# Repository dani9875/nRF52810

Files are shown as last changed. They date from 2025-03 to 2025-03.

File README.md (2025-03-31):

# nRF52810
Basic HW and FW to setup nRF developer environment

# Instructions

1. Clone the repository:
```bash
git clone <repository-url>
```

2. Build the Docker image (requires sudo permissions):
```bash
sudo ./docker_build.sh
```
3. Start the Docker container:

```bash
./docker_start.sh
```

4. Enter the project root folder (you should already be in the correct directory).

5. Initialize the West workspace:
```bash
west init -l app
```

6. Update west modules (this step can take a few minutes)
```bash
west update
```

7. Export Zephyr environment:
```bash
west zephyr-export
```

8. Build the application for the nRF52840 DK:
```bash
west build -b nrf52840dk/nrf52840 app
```

## Release notes

### Version: v2.0-test phase
Changelog:
- 2.4 GHz antenna design
- LED for blinky funtionality
- Plug of nails changed to pluggable
- Optical sensor added
- 3V3 and 1V9 power rails
- KiCAD library commit: f8f82b3228b9b2e6a28c75499dfac7be01fe0e7f

### Version: v1.0
Changelog:
- Minimal env. for bringing an nRF52810 up
- LED for blinky functionality
- Tactile button for user input
- LDO power adjustment
- Plug of nails footprint faulty

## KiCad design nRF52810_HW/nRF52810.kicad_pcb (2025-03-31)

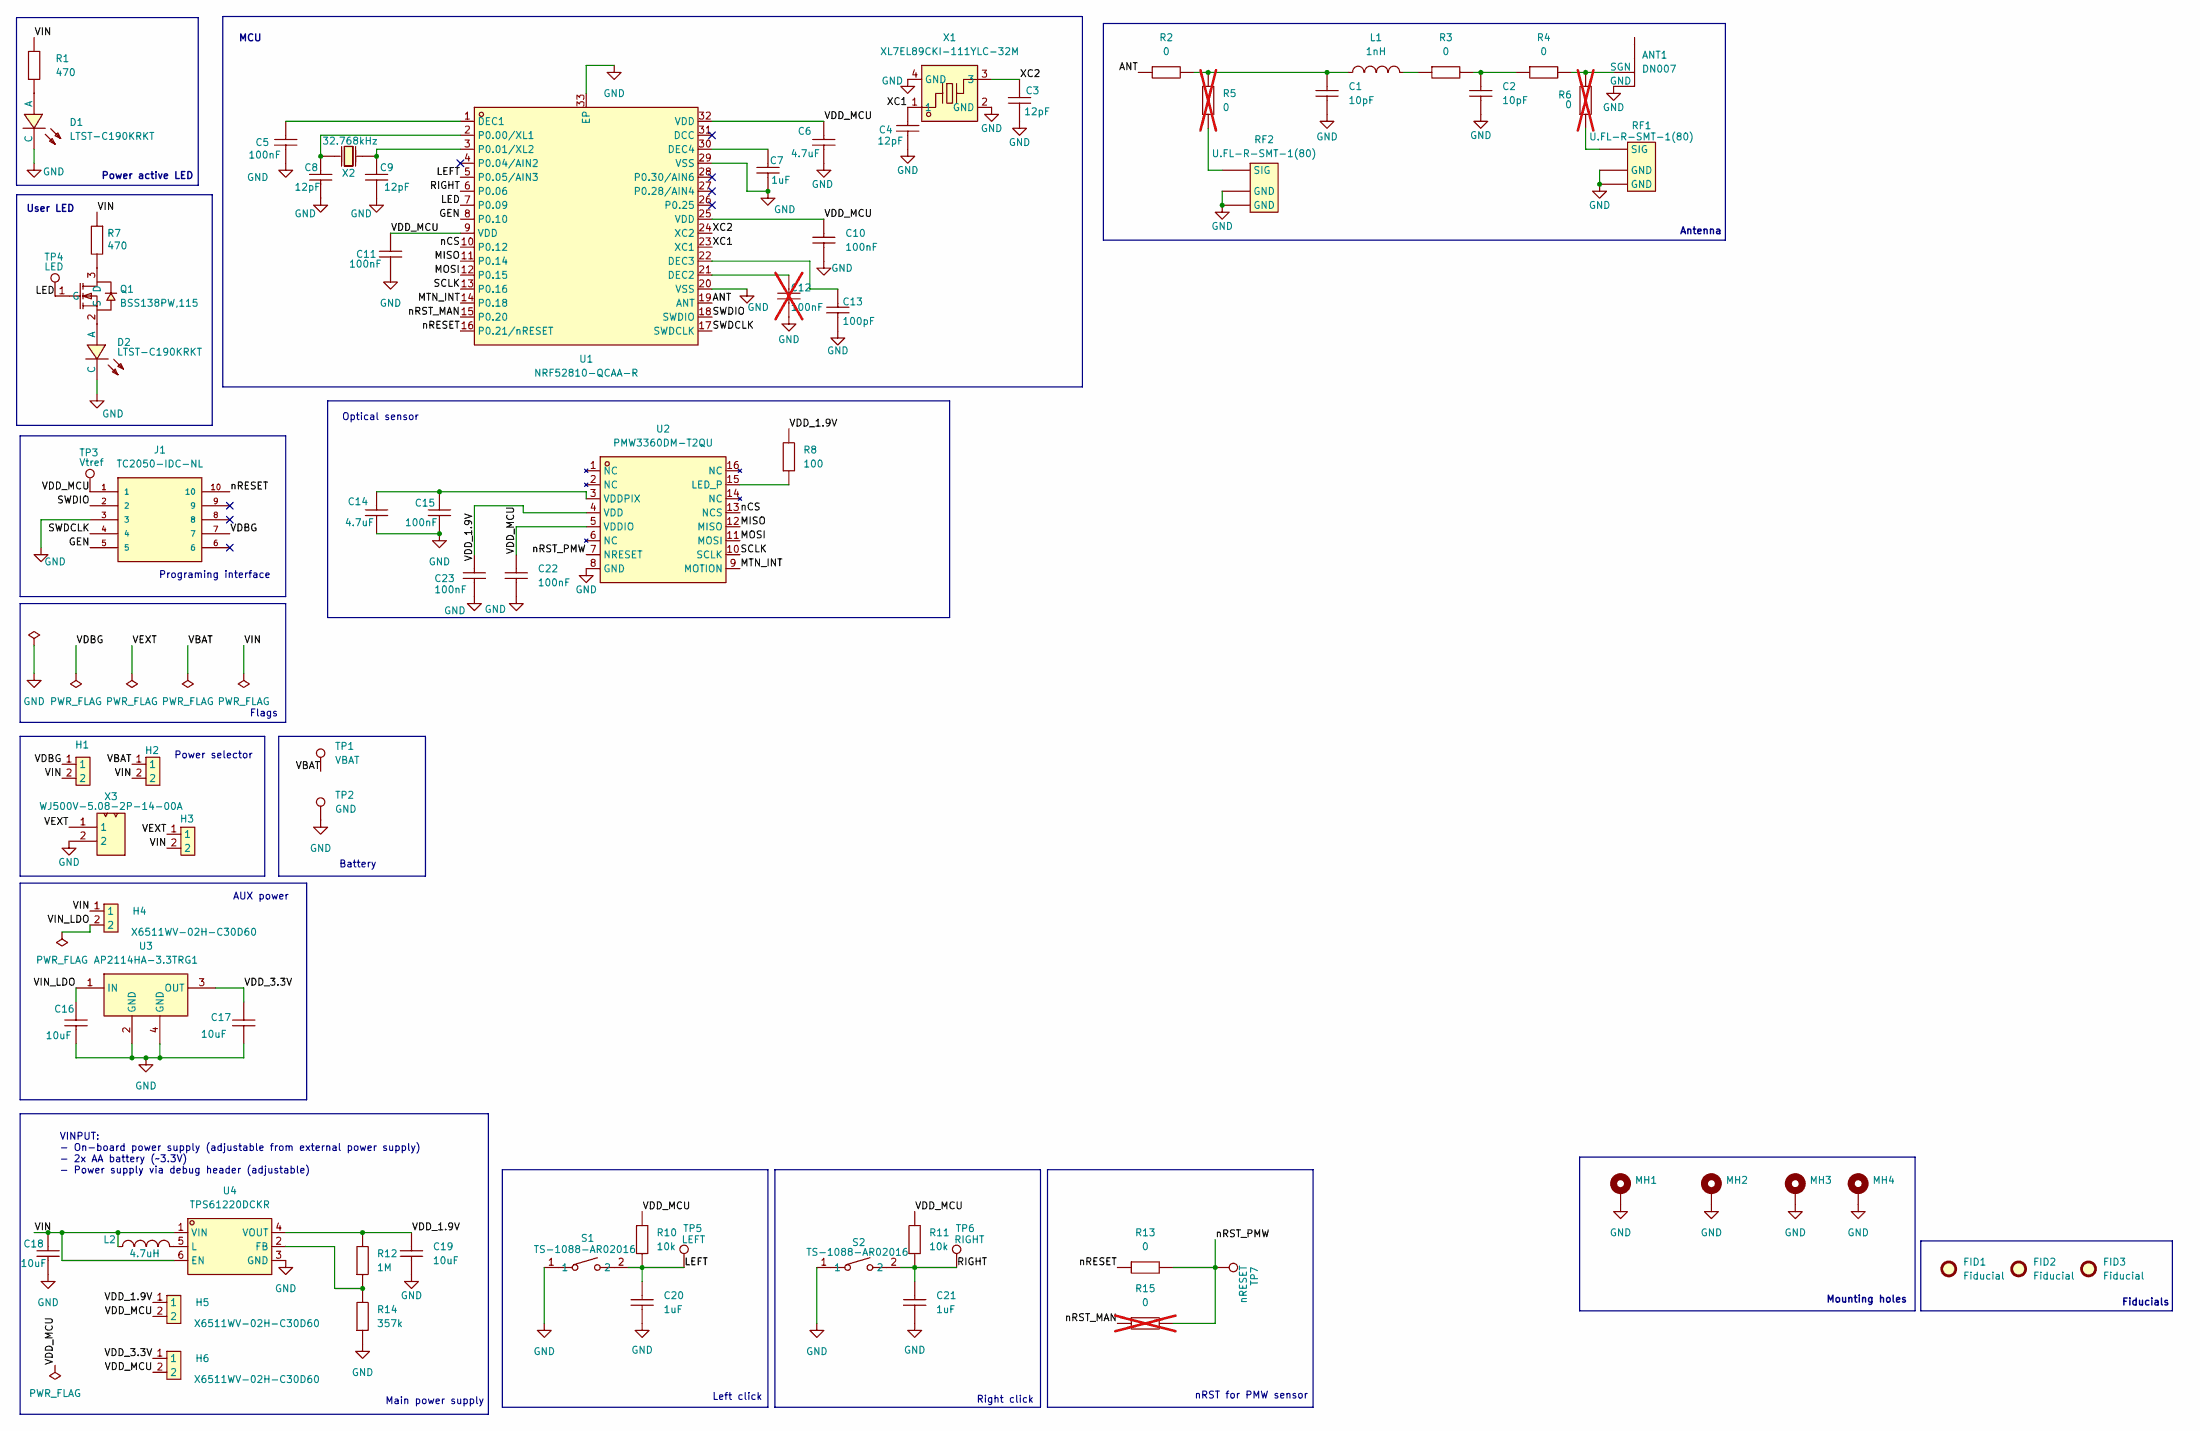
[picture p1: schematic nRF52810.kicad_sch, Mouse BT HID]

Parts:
ANT1: DN007; [ANTENNA]DN007_1,2.4GHz
C1, C2: C0805C100K5GACTU; [CAP_SMD_0805_2012Metric]; LCSC Part C2181972
C3, C4, C8, C9: C0805C120J5GACAUTO; [CAP_SMD_0805_2012Metric]; LCSC Part C3844403
C5, C10, C11, C15, C22, C23: CC0805KRX7R9BB104; [CAP_SMD_0805_2012Metric]; LCSC Part C49678
C6, C14: CL21A475KAQNNNE; [CAP_SMD_0805_2012Metric]; LCSC Part C1779
C7, C20, C21: C0805C105M4VACTU; [CAP_SMD_0805_2012Metric]; LCSC Part C2171722
C12: CC0805KRX7R9BB104; [CAP_SMD_0805_2012Metric]; LCSC Part C49678; not fitted
C13: C0805C101K5GACTU; [CAP_SMD_0805_2012Metric]; LCSC Part C452752
C16, C17, C18, C19: CL21A106KOQNNNE; [CAP_SMD_0805_2012Metric]; LCSC Part C1713
D1, D2: LTST-C190KRKT; [LED]Lite-On LTST-C190KRKT; LCSC Part C94869
FID1, FID2, FID3: Fiducial; Fiducial_0.5mm_Mask1mm
H1, H2, H3, H4, H5, H6: X6511WV-02H-C30D60; [2x1_PIN_HEADER_STR]XKB Connection X6511WV-02H-C60D30; LCSC Part C706874
J1: TC2050-IDC-NL; [PLUG_OF_NAILS_10P]TC2050_IDC_NL; PARTREV A
L1: LQG15HS1N0S02D; [IND_SMD_0402_1005Metric]; LCSC Part C18222
L2: FNR3015S4R7MT; [POWER_IND]cjiang (Changjiang Microelectronics Tech) FNR301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; LCSC Part C167753
MH1, MH2, MH3, MH4: [MOUNTING_HOLE]MountingHole_2.2mm_M2_DIN965_Pad
Q1: BSS138PW,115; [NMOS]Nexperia BSS138PW,115; LCSC Part C193366
R1, R7: 0805W8F4700T5E; [RES_SMD_0805_2012Metric]; LCSC Part C17710
R2, R3, R4: 0402WGF0000TCE; [RES_SMD_0402_1005Metric]; LCSC Part C17168
R5, R6: 0402WGF0000TCE; [RES_SMD_0402_1005Metric]; LCSC Part C17168; not fitted
R8: 0805W8F1000T5E; [RES_SMD_0805_2012Metric]; LCSC Part C17408
R10, R11: 0805W8F1002T5E; [RES_SMD_0805_2012Metric]; LCSC Part C17414
R12: 0805W8F1004T5E; [RES_SMD_0805_2012Metric]; LCSC Part C17514
R13: 0805W8F0000T5E; [RES_SMD_0805_2012Metric]; LCSC Part C17673
R14: RK73H2ATTD3573F; [RES_SMD_0805_2012Metric]; LCSC Part C317468
R15: 0805W8F0000T5E; [RES_SMD_0805_2012Metric]; LCSC Part C17673; not fitted
RF1, RF2: U.FL-R-SMT-1(80); [SMD_COAXIAL_CONNECTOR]HRS(Hirose) U.FL-R-SMT-1(80); LCSC Part C88374
S1, S2: TS-1088-AR02016; [TACTILE_SWITCH]XUNPU TS-1088-AR02016; LCSC Part C720477
TP1: VBAT; [TEST_POINT]TestPoint_Pad_2.0x2.0mm
TP2: GND; [TEST_POINT]TestPoint_Pad_2.0x2.0mm
TP3: Vtref; [TEST_POINT]TestPoint_Pad_D1.0mm
TP4: LED; [TEST_POINT]TestPoint_Pad_D1.0mm
TP5: LEFT; [TEST_POINT]TestPoint_Pad_D1.0mm
TP6: RIGHT; [TEST_POINT]TestPoint_Pad_D1.0mm
TP7: nRESET; [TEST_POINT]TestPoint_Pad_D1.0mm
U1: NRF52810-QCAA-R; [MCU]Nordic Semicon nRF52810-QCAA-R; LCSC Part C519278
U2: PMW3360DM-T2QU; [OPTICAL_NAVIGATION_CHIP]PixArt PMW3360DM-T2QU; LCSC Part C20612443
U3: AP2114HA-3.3TRG1; [LDO]Diodes Incorporated AP2114HA-3.3TRG1; LCSC Part C460314
U4: TPS61220DCKR; [BOOST_CONV]Texas Instruments TPS61220DCKR; LCSC Part C15421
X1: XL7EL89CKI-111YLC-32M; [Crystal_32_MHz]YXC XL7EL89CKI-111YLC-32M; LCSC Part C2965582
X2: SC-20S32.768kHz20PPM9pF; [Crystal_32_768_kHZ]Seiko SC-20S,32.768kHz,20PPM,9pF; LCSC Part C97603
X3: WJ500V-5.08-2P-14-00A; [1x2_SCREW_TERMINAL_BLOCK]Ningbo Kangnex Elec WJ500V-5.08-2P; LCSC Part C8465

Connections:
/ANT: R2.1, U1.19 (ANT)
/GEN: J1.5, U1.8 (P0.10)
/LED: Q1.1 (G), TP4.1, U1.7 (P0.09)
/LEFT: C20.2, R10.1, S1.2, TP5.1, U1.5 (P0.05/AIN3)
/MISO: U1.11 (P0.14), U2.12 (MISO)
/MOSI: U1.12 (P0.15), U2.11 (MOSI)
/MTN_INT: U1.14 (P0.18), U2.9 (MOTION)
/RIGHT: C21.2, R11.1, S2.2, TP6.1, U1.6 (P0.06)
/SCLK: U1.13 (P0.16), U2.10 (SCLK)
/SWDCLK: J1.4, U1.17 (SWDCLK)
/SWDIO: J1.2, U1.18 (SWDIO)
/VBAT: H2.1, TP1.1
/VDBG: H1.1, J1.7
/VDD_1.9V: C19.2, C23.2, H5.1, R8.2, R12.2, U2.4 (VDD), U4.4 (VOUT)
/VDD_3.3V: C17.2, H6.1, U3.3 (OUT)
/VDD_MCU: C6.2, C10.2, C11.2, C22.2, H5.2, H6.2, J1.1, R10.2, R11.2, TP3.1, U1.9 (VDD), U1.25 (VDD), U1.32 (VDD), U2.5 (VDDIO)
/VEXT: H3.1, X3.1
/VIN: C18.2, H1.2, H2.2, H3.2, H4.1, L2.2, R1.1, R7.1, U4.1 (VIN), U4.6 (EN)
/VIN_LDO: C16.2, H4.2, U3.1 (IN)
/XC1: C4.2, U1.23 (XC1), X1.1
/XC2: C3.2, U1.24 (XC2), X1.3
/nCS: U1.10 (P0.12), U2.13 (NCS)
/nRESET: J1.10, R13.1, U1.16 (P0.21/nRESET)
/nRST_MAN: R15.1, U1.15 (P0.20)
/nRST_PMW: R13.2, R15.2, TP7.1, U2.7 (NRESET)
GND: ANT1.1 (GND), C1.1, C2.1, C3.1, C4.1, C5.1, C6.1, C7.1, C8.1, C9.1, C10.1, C11.1, C12.1, C13.1, C14.2, C15.1, C16.1, C17.1, C18.1, C19.1, C20.1, C21.1, C22.1, C23.1, D1.2 (C), D2.2 (C), J1.3, MH1.1, MH2.1, MH3.1, MH4.1, R14.1, RF1.2 (GND), RF1.3 (GND), RF2.2 (GND), RF2.3 (GND), S1.1, S2.1, TP2.1, U1.20 (VSS), U1.29 (VSS), U1.33 (EP), U2.8 (GND), U3.2 (GND), U3.4 (GND), U4.3 (GND), X1.2 (GND), X1.4 (GND), X3.2
unnamed: ANT1.2 (SGN), R4.2, R6.2
unnamed: C1.2, L1.2, R2.2, R5.2
unnamed: C2.2, R3.2, R4.1
unnamed: D1.1 (A), R1.2
unnamed: D2.1 (A), Q1.2 (S)
unnamed: L1.1, R3.1
unnamed: Q1.3 (D), R7.2
unnamed: R6.1, RF1.1 (SIG)
unnamed: R5.1, RF2.1 (SIG)
unnamed: C5.2, U1.1 (DEC1)
unnamed: C12.2, U1.21 (DEC2)
unnamed: C13.2, U1.22 (DEC3)
unnamed: C7.2, U1.30 (DEC4)
unnamed: C8.2, U1.2 (P0.00/XL1), X2.1
unnamed: C9.2, U1.3 (P0.01/XL2), X2.2
unnamed: R8.1, U2.15 (LED_P)
unnamed: C14.1, C15.2, U2.3 (VDDPIX)
unnamed: R12.1, R14.2, U4.2 (FB)
unnamed: L2.1, U4.5 (L)

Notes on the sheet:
Right click
User LED
Power active LED
nRST for PMW sensor
Programing interface
Left click
Flags
Mounting holes
Fiducials
Antenna
Optical sensor
AUX power
MCU
VINPUT: - On-board power supply (adjustable from external power supply) - 2x AA battery (~3.3V) - Power supply via debug header (adjustable)
Main power supply
Power selector
Battery

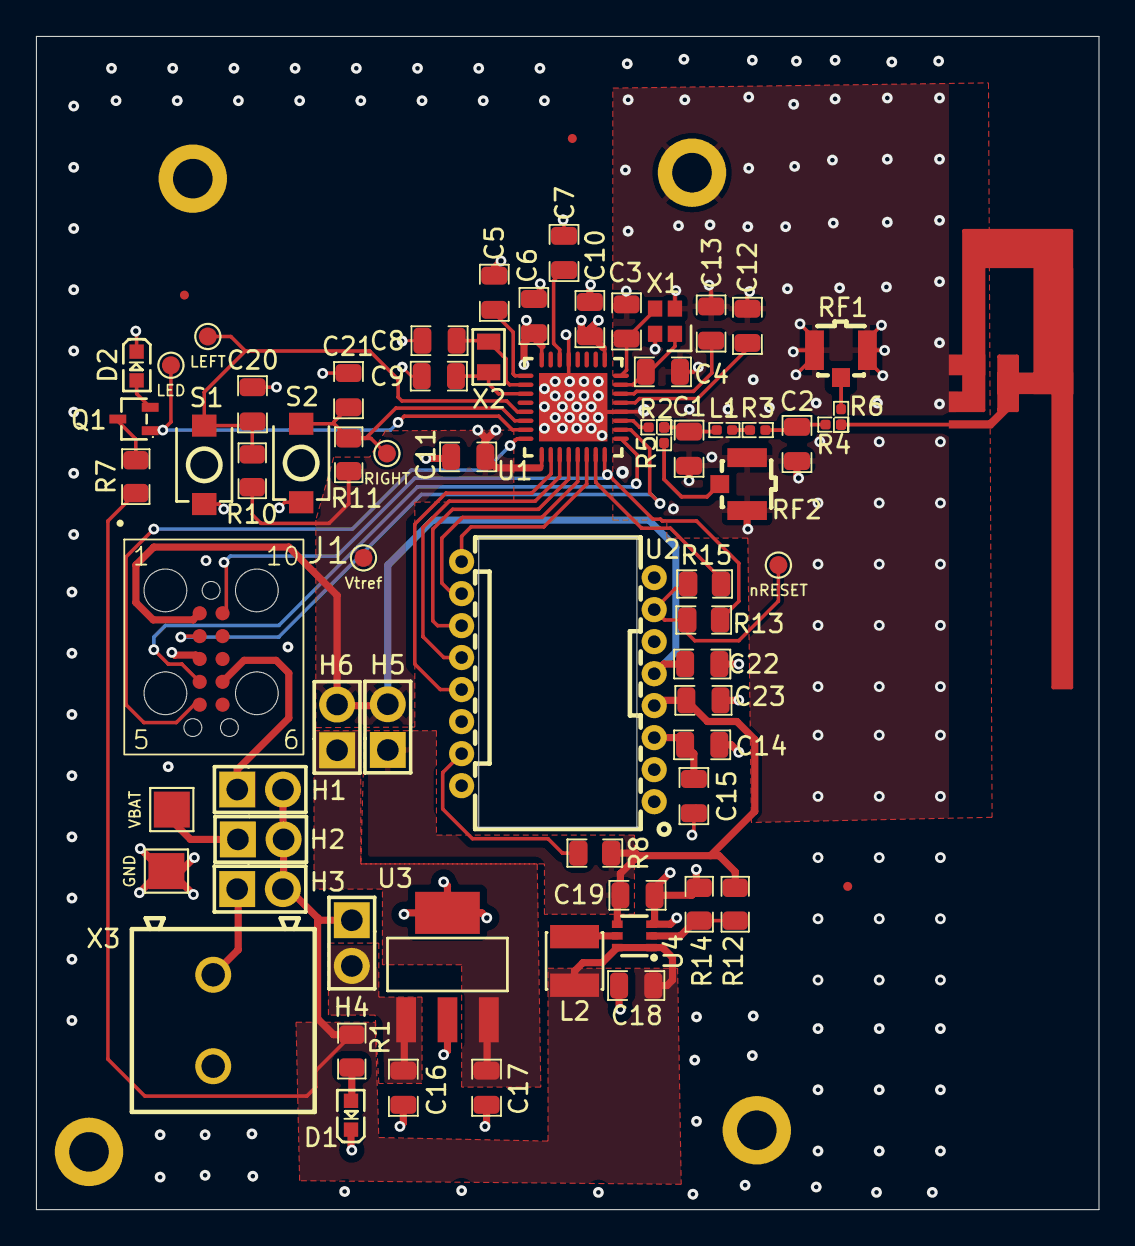
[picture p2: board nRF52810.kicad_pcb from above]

Board: 4 copper layers, 59.0 x 65.2 mm, 75 parts (0 on the bottom side), 45 nets.

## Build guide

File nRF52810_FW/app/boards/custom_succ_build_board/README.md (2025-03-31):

# Custom Plank Board

`custom_plank` board is used to demonstrate how to create custom boards. It is
in fact a simplified version of the nRF52840-DK board, so the
`example-application` can be run on that development kit when using
`custom_plank`.

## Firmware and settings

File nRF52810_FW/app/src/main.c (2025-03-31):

/*
 * Copyright (c) 2018 Nordic Semiconductor ASA
 *
 * SPDX-License-Identifier: LicenseRef-Nordic-5-Clause
 */

#include <zephyr/types.h>
#include <stddef.h>
#include <string.h>
#include <errno.h>
// #include <zephyr/logging/log.h>
#include <zephyr/device.h>
#include <zephyr/sys/printk.h>
#include <zephyr/sys/byteorder.h>
#include <zephyr/kernel.h>
#include <zephyr/drivers/gpio.h>
#include <soc.h>
#include <assert.h>


#include <zephyr/bluetooth/bluetooth.h>
#include <zephyr/bluetooth/uuid.h>
#include <zephyr/bluetooth/gatt.h>
#include <zephyr/bluetooth/hci.h>

#include <zephyr/settings/settings.h>
#define DEVICE_NAME		"Remote"
#define DEVICE_NAME_LEN		(sizeof(DEVICE_NAME) - 1)


#define LED_NODE DT_ALIAS(led0)
#if !DT_NODE_HAS_STATUS(LED_NODE, okay)
#error "Unsupported board: led0 devicetree alias is not defined"
#endif

// #define PMW3360_DEFINE(n)						       \
// 	static struct pmw3360_data data##n;				       \
// 									       \
// 	static const struct pmw3360_config config##n = {		       \
// 		.irq_gpio = GPIO_DT_SPEC_INST_GET(n, irq_gpios),	       \
// 		.bus = {						       \
// 			.bus = DEVICE_DT_GET(DT_INST_BUS(n)),		       \
// 			.config = {					       \
// 				.frequency = DT_INST_PROP(n,		       \
// 							  spi_max_frequency),  \
// 				.operation = SPI_WORD_SET(8) |		       \
// 					     SPI_TRANSFER_MSB |		       \
// 					     SPI_MODE_CPOL | SPI_MODE_CPHA,    \
// 				.slave = DT_INST_REG_ADDR(n),		       \
// 			},						       \
// 		},							       \
// 		.cs_gpio = SPI_CS_GPIOS_DT_SPEC_GET(DT_DRV_INST(n)),	       \
// 	};								       \
// 									       \
// 	DEVICE_DT_INST_DEFINE(n, pmw3360_init, NULL, &data##n, &config##n,     \
// 			      POST_KERNEL, CONFIG_SENSOR_INIT_PRIORITY,	       \
// 			      &pmw3360_driver_api);

// DT_INST_FOREACH_STATUS_OKAY(PMW3360_DEFINE)






/** @brief UUID of the Remote Service. **/
#define BT_UUID_REMOTE_SERV_VAL \
	BT_UUID_128_ENCODE(0xe9ea0001, 0xe19b, 0x482d, 0x9293, 0xc7907585fc48)

/** @brief UUID of the Button Characteristic. **/
#define BT_UUID_REMOTE_BUTTON_CHRC_VAL \
	BT_UUID_128_ENCODE(0xe9ea0002, 0xe19b, 0x482d, 0x9293, 0xc7907585fc48)

/** @brief UUID of the Message Characteristic. **/
#define BT_UUID_REMOTE_MESSAGE_CHRC_VAL \
	BT_UUID_128_ENCODE(0xe9ea0003, 0xe19b, 0x482d, 0x9293, 0xc7907585fc48)

#define BT_UUID_REMOTE_SERVICE          BT_UUID_DECLARE_128(BT_UUID_REMOTE_SERV_VAL)
#define BT_UUID_REMOTE_BUTTON_CHRC 	    BT_UUID_DECLARE_128(BT_UUID_REMOTE_BUTTON_CHRC_VAL)
#define BT_UUID_REMOTE_MESSAGE_CHRC     BT_UUID_DECLARE_128(BT_UUID_REMOTE_MESSAGE_CHRC_VAL)

static const struct bt_data ad[] = {
    BT_DATA_BYTES(BT_DATA_FLAGS, (BT_LE_AD_GENERAL | BT_LE_AD_NO_BREDR)),
    BT_DATA(BT_DATA_NAME_COMPLETE, DEVICE_NAME, DEVICE_NAME_LEN)
};

static const struct bt_data sd[] = {
    BT_DATA_BYTES(BT_DATA_UUID128_ALL, BT_UUID_REMOTE_SERV_VAL),
};

enum bt_button_notifications_enabled {
	BT_BUTTON_NOTIFICATIONS_ENABLED,
	BT_BUTTON_NOTIFICATIONS_DISABLED,
};

struct bt_remote_service_cb {
	void (*notif_changed)(enum bt_button_notifications_enabled status);
    void (*data_received)(struct bt_conn *conn, const uint8_t *const data, uint16_t len);
};

static K_SEM_DEFINE(bt_init_ok, 1, 1);

static const struct gpio_dt_spec led = GPIO_DT_SPEC_GET(LED_NODE, gpios);

static struct bt_remote_service_cb remote_callbacks;

static struct bt_conn *current_conn;

/* Declarations */
void on_connected(struct bt_conn *conn, uint8_t err);
void on_disconnected(struct bt_conn *conn, uint8_t reason);
void on_notif_changed(enum bt_button_notifications_enabled status);
void on_data_received(struct bt_conn *conn, const uint8_t *const data, uint16_t len);

struct bt_conn_cb bluetooth_callbacks = {
	.connected 		= on_connected,
	.disconnected 	= on_disconnected,
};
struct bt_remote_service_cb remote_callbacks_s = {
	.notif_changed = on_notif_changed,
    .data_received = on_data_received,
};

/**************************************************************/
extern const uint8_t pmw3360_firmware_data[];

#define DT_DRV_COMPAT pixart_pmw3360

#include <zephyr/kernel.h>
#include <zephyr/drivers/sensor.h>
#include <zephyr/device.h>
#include <zephyr/drivers/spi.h>
#include <zephyr/drivers/gpio.h>
#include <zephyr/sys/byteorder.h>
#include <sensor/pmw3360.h>

#include <zephyr/logging/log.h>
LOG_MODULE_REGISTER(pmw3360, 0);

/* Timings defined by spec */
#define T_NCS_SCLK	1			/* 120 ns */
#define T_SRX		(20 - T_NCS_SCLK)	/* 20 us */
#define T_SCLK_NCS_WR	(35 - T_NCS_SCLK)	/* 35 us */
#define T_SWX		(180 - T_SCLK_NCS_WR)	/* 180 us */
#define T_SRAD		160			/* 160 us */
#define T_SRAD_MOTBR	35			/* 35 us */
#define T_BEXIT		1			/* 500 ns */

/* Timing defined on SROM download burst mode figure */
#define T_BRSEP		15			/* 15 us */


/* Sensor registers */
#define PMW3360_REG_PRODUCT_ID			0x00
#define PMW3360_REG_REVISION_ID			0x01
#define PMW3360_REG_MOTION			0x02
#define PMW3360_REG_DELTA_X_L			0x03
#define PMW3360_REG_DELTA_X_H			0x04
#define PMW3360_REG_DELTA_Y_L			0x05
#define PMW3360_REG_DELTA_Y_H			0x06
#define PMW3360_REG_SQUAL			0x07
#define PMW3360_REG_RAW_DATA_SUM		0x08
#define PMW3360_REG_MAXIMUM_RAW_DATA		0x09
#define PMW3360_REG_MINIMUM_RAW_DATA		0x0A
#define PMW3360_REG_SHUTTER_LOWER		0x0B
#define PMW3360_REG_SHUTTER_UPPER		0x0C
#define PMW3360_REG_CONTROL			0x0D
#define PMW3360_REG_CONFIG1			0x0F
#define PMW3360_REG_CONFIG2			0x10
#define PMW3360_REG_ANGLE_TUNE			0x11
#define PMW3360_REG_FRAME_CAPTURE		0x12
#define PMW3360_REG_SROM_ENABLE			0x13
#define PMW3360_REG_RUN_DOWNSHIFT		0x14
#define PMW3360_REG_REST1_RATE_LOWER		0x15
#define PMW3360_REG_REST1_RATE_UPPER		0x16
#define PMW3360_REG_REST1_DOWNSHIFT		0x17
#define PMW3360_REG_REST2_RATE_LOWER		0x18
#define PMW3360_REG_REST2_RATE_UPPER		0x19
#define PMW3360_REG_REST2_DOWNSHIFT		0x1A
#define PMW3360_REG_REST3_RATE_LOWER		0x1B
#define PMW3360_REG_REST3_RATE_UPPER		0x1C
#define PMW3360_REG_OBSERVATION			0x24
#define PMW3360_REG_DATA_OUT_LOWER		0x25
#define PMW3360_REG_DATA_OUT_UPPER		0x26
#define PMW3360_REG_RAW_DATA_DUMP		0x29
#define PMW3360_REG_SROM_ID			0x2A
#define PMW3360_REG_MIN_SQ_RUN			0x2B
#define PMW3360_REG_RAW_DATA_THRESHOLD		0x2C
#define PMW3360_REG_CONFIG5			0x2F
#define PMW3360_REG_POWER_UP_RESET		0x3A
#define PMW3360_REG_SHUTDOWN			0x3B
#define PMW3360_REG_INVERSE_PRODUCT_ID		0x3F
#define PMW3360_REG_LIFTCUTOFF_TUNE3		0x41
#define PMW3360_REG_ANGLE_SNAP			0x42
#define PMW3360_REG_LIFTCUTOFF_TUNE1		0x4A
#define PMW3360_REG_MOTION_BURST		0x50
#define PMW3360_REG_LIFTCUTOFF_TUNE_TIMEOUT	0x58
#define PMW3360_REG_LIFTCUTOFF_TUNE_MIN_LENGTH	0x5A
#define PMW3360_REG_SROM_LOAD_BURST		0x62
#define PMW3360_REG_LIFT_CONFIG			0x63
#define PMW3360_REG_RAW_DATA_BURST		0x64
#define PMW3360_REG_LIFTCUTOFF_TUNE2		0x65

/* Sensor identification values */
#define PMW3360_PRODUCT_ID			0x42
#define PMW3360_FIRMWARE_ID			0x04

/* Max register count readable in a single motion burst */
#define PMW3360_MAX_BURST_SIZE			12

/* Register count used for reading a single motion burst */
#define PMW3360_BURST_SIZE			6

/* Position of X in motion burst data */
#define PMW3360_DX_POS				2
#define PMW3360_DY_POS				4

/* Rest_En position in Config2 register. */
#define PMW3360_REST_EN_POS			5

#define PMW3360_MAX_CPI				12000
#define PMW3360_MIN_CPI				100


#define SPI_WRITE_BIT				BIT(7)

/* Helper macros used to convert sensor values. */
#define PMW3360_SVALUE_TO_CPI(svalue) ((uint32_t)(svalue).val1)
#define PMW3360_SVALUE_TO_TIME(svalue) ((uint32_t)(svalue).val1)
#define PMW3360_SVALUE_TO_BOOL(svalue) ((svalue).val1 != 0)


extern const size_t pmw3360_firmware_length;
extern const uint8_t pmw3360_firmware_data[];


enum async_init_step {
	ASYNC_INIT_STEP_POWER_UP,
	ASYNC_INIT_STEP_FW_LOAD_START,
	ASYNC_INIT_STEP_FW_LOAD_CONTINUE,
	ASYNC_INIT_STEP_FW_LOAD_VERIFY,
	ASYNC_INIT_STEP_CONFIGURE,

	ASYNC_INIT_STEP_COUNT
};

struct pmw3360_data {
	const struct device          *dev;
	struct gpio_callback         irq_gpio_cb;
	struct k_spinlock            lock;
	int16_t                      x;
	int16_t                      y;
	sensor_trigger_handler_t     data_ready_handler;
	struct k_work                trigger_handler_work;
	struct k_work_delayable      init_work;
	enum async_init_step         async_init_step;
	int                          err;
	bool                         ready;
	bool                         last_read_burst;
};

struct pmw3360_config {
	struct gpio_dt_spec irq_gpio;
	struct spi_dt_spec bus;
	struct gpio_dt_spec cs_gpio;
};

static const int32_t async_init_delay[ASYNC_INIT_STEP_COUNT] = {
	[ASYNC_INIT_STEP_POWER_UP]         = 1,
	[ASYNC_INIT_STEP_FW_LOAD_START]    = 50,
	[ASYNC_INIT_STEP_FW_LOAD_CONTINUE] = 10,
	[ASYNC_INIT_STEP_FW_LOAD_VERIFY]   = 1,
	[ASYNC_INIT_STEP_CONFIGURE]        = 0,
};


static int pmw3360_async_init_power_up(const struct device *dev);
static int pmw3360_async_init_configure(const struct device *dev);
static int pmw3360_async_init_fw_load_verify(const struct device *dev);
static int pmw3360_async_init_fw_load_continue(const struct device *dev);
static int pmw3360_async_init_fw_load_start(const struct device *dev);

static int (* const async_init_fn[ASYNC_INIT_STEP_COUNT])(const struct device *dev) = {
	[ASYNC_INIT_STEP_POWER_UP] = pmw3360_async_init_power_up,
	[ASYNC_INIT_STEP_FW_LOAD_START] = pmw3360_async_init_fw_load_start,
	[ASYNC_INIT_STEP_FW_LOAD_CONTINUE] = pmw3360_async_init_fw_load_continue,
	[ASYNC_INIT_STEP_FW_LOAD_VERIFY] = pmw3360_async_init_fw_load_verify,
	[ASYNC_INIT_STEP_CONFIGURE] = pmw3360_async_init_configure,
};

static int spi_cs_ctrl(const struct device *dev, bool enable)
{
	const struct pmw3360_config *config = dev->config;
	int err;

	if (!enable) {
		k_busy_wait(T_NCS_SCLK);
	}

	err = gpio_pin_set_dt(&config->cs_gpio, (int)enable);
	if (err) {
		printk("SPI CS ctrl failed");
	}

	if (enable) {
		k_busy_wait(T_NCS_SCLK);
	}

	return err;
}

static int reg_read(const struct device *dev, uint8_t reg, uint8_t *buf)
{
	int err;
	struct pmw3360_data *data = dev->data;
	const struct pmw3360_config *config = dev->config;

	__ASSERT_NO_MSG((reg & SPI_WRITE_BIT) == 0);

	err = spi_cs_ctrl(dev, true);
	if (err) {
		return err;
	}

	/* Write register address. */
	const struct spi_buf tx_buf = {
		.buf = &reg,
		.len = 1
	};
	const struct spi_buf_set tx = {
		.buffers = &tx_buf,
		.count = 1
	};

	err = spi_write_dt(&config->bus, &tx);
	if (err) {
		printk("Reg read failed on SPI write");
		return err;
	}

	k_busy_wait(T_SRAD);

	/* Read register value. */
	struct spi_buf rx_buf = {
		.buf = buf,
		.len = 1,
	};
	const struct spi_buf_set rx = {
		.buffers = &rx_buf,
		.count = 1,
	};

	err = spi_read_dt(&config->bus, &rx);
	if (err) {
		printk("Reg read failed on SPI read");
		return err;
	}

	err = spi_cs_ctrl(dev, false);
	if (err) {
		return err;
	}

	k_busy_wait(T_SRX);

	data->last_read_burst = false;

	return 0;
}

static int reg_write(const struct device *dev, uint8_t reg, uint8_t val)
{
	int err;
	struct pmw3360_data *data = dev->data;
	const struct pmw3360_config *config = dev->config;

	__ASSERT_NO_MSG((reg & SPI_WRITE_BIT) == 0);

	err = spi_cs_ctrl(dev, true);
	if (err) {
		return err;
	}

	uint8_t buf[] = {
		SPI_WRITE_BIT | reg,
		val
	};
	const struct spi_buf tx_buf = {
		.buf = buf,
		.len = ARRAY_SIZE(buf)
	};
	const struct spi_buf_set tx = {
		.buffers = &tx_buf,
		.count = 1
	};

	err = spi_write_dt(&config->bus, &tx);
	if (err) {
		printk("Reg write failed on SPI write");
		return err;
	}

	k_busy_wait(T_SCLK_NCS_WR);

	err = spi_cs_ctrl(dev, false);
	if (err) {
		return err;
	}

	k_busy_wait(T_SWX);

	data->last_read_burst = false;

	return 0;
}

static int motion_burst_read(const struct device *dev, uint8_t *buf,
			     size_t burst_size)
{
	int err;
	struct pmw3360_data *data = dev->data;
	const struct pmw3360_config *config = dev->config;

	__ASSERT_NO_MSG(burst_size <= PMW3360_MAX_BURST_SIZE);

	/* Write any value to motion burst register only if there have been
	 * other SPI transmissions with sensor since last burst read.
	 */
	if (!data->last_read_burst) {
		err = reg_write(dev, PMW3360_REG_MOTION_BURST, 0x00);
		if (err) {
			return err;
		}
	}

	err = spi_cs_ctrl(dev, true);
	if (err) {
		return err;
	}

	/* Send motion burst address */
	uint8_t reg_buf[] = {
		PMW3360_REG_MOTION_BURST
	};
	const struct spi_buf tx_buf = {
		.buf = reg_buf,
		.len = ARRAY_SIZE(reg_buf)
	};
	const struct spi_buf_set tx = {
		.buffers = &tx_buf,
		.count = 1
	};

	err = spi_write_dt(&config->bus, &tx);
	if (err) {
		printk("Motion burst failed on SPI write");
		return err;
	}

	k_busy_wait(T_SRAD_MOTBR);

	const struct spi_buf rx_buf = {
		.buf = buf,
		.len = burst_size,
	};
	const struct spi_buf_set rx = {
		.buffers = &rx_buf,
		.count = 1
	};

	err = spi_read_dt(&config->bus, &rx);
	if (err) {
		printk("Motion burst failed on SPI read");
		return err;
	}

	/* Terminate burst */
	err = spi_cs_ctrl(dev, false);
	if (err) {
		return err;
	}

	k_busy_wait(T_BEXIT);

	data->last_read_burst = true;

	return 0;
}

static int burst_write(const struct device *dev, uint8_t reg, const uint8_t *buf,
		       size_t size)
{
	int err;
	struct pmw3360_data *data = dev->data;
	const struct pmw3360_config *config = dev->config;

	/* Write address of burst register */
	uint8_t write_buf = reg | SPI_WRITE_BIT;
	struct spi_buf tx_buf = {
		.buf = &write_buf,
		.len = 1
	};
	const struct spi_buf_set tx = {
		.buffers = &tx_buf,
		.count = 1
	};

	err = spi_cs_ctrl(dev, true);
	if (err) {
		return err;
	}

	err = spi_write_dt(&config->bus, &tx);
	if (err) {
		printk("Burst write failed on SPI write");
		return err;
	}

	/* Write data */
	for (size_t i = 0; i < size; i++) {
		write_buf = buf[i];

		err = spi_write_dt(&config->bus, &tx);
		if (err) {
			printk("Burst write failed on SPI write (data)");
			return err;
		}

		k_busy_wait(T_BRSEP);
	}

	/* Terminate burst mode. */
	err = spi_cs_ctrl(dev, false);
	if (err) {
		return err;
	}

	k_busy_wait(T_BEXIT);

	data->last_read_burst = false;

	return 0;
}

static int update_cpi(const struct device *dev, uint32_t cpi)
{
	/* Set resolution with CPI step of 100 cpi
	 * 0x00: 100 cpi (minimum cpi)
	 * 0x01: 200 cpi
	 * :
	 * 0x31: 5000 cpi (default cpi)
	 * :
	 * 0x77: 12000 cpi (maximum cpi)
	 */

	if ((cpi > PMW3360_MAX_CPI) || (cpi < PMW3360_MIN_CPI)) {
		printk("CPI value %u out of range", cpi);
		return -EINVAL;
	}

	/* Convert CPI to register value */
	uint8_t value = (cpi / 100) - 1;

	printk("Setting CPI to %u (reg value 0x%x)", cpi, value);

	int err = reg_write(dev, PMW3360_REG_CONFIG1, value);
	if (err) {
		printk("Failed to change CPI");
	}

	return err;
}

static int update_downshift_time(const struct device *dev, uint8_t reg_addr,
				 uint32_t time)
{
	/* Set downshift time:
	 * - Run downshift time (from Run to Rest1 mode)
	 * - Rest 1 downshift time (from Rest1 to Rest2 mode)
	 * - Rest 2 downshift time (from Rest2 to Rest3 mode)
	 */
	uint32_t maxtime;
	uint32_t mintime;

	switch (reg_addr) {
	case PMW3360_REG_RUN_DOWNSHIFT:
		/*
		 * Run downshift time = PMW3360_REG_RUN_DOWNSHIFT * 10 ms
		 */
		maxtime = 2550;
		mintime = 10;
		break;

	case PMW3360_REG_REST1_DOWNSHIFT:
		/*
		 * Rest1 downshift time = PMW3360_REG_RUN_DOWNSHIFT
		 *                        * 320 * Rest1 rate (default 1 ms)
		 */
		maxtime = 81600;
		mintime = 320;
		break;

	case PMW3360_REG_REST2_DOWNSHIFT:
		/*
		 * Rest2 downshift time = PMW3360_REG_REST2_DOWNSHIFT
		 *                        * 32 * Rest2 rate (default 100 ms)
		 */
		maxtime = 816000;
		mintime = 3200;
		break;

	default:
		printk("Not supported");
		return -ENOTSUP;
	}

	if ((time > maxtime) || (time < mintime)) {
		printk("Downshift time %u out of range", time);
		return -EINVAL;
	}

	__ASSERT_NO_MSG((mintime > 0) && (maxtime/mintime <= UINT8_MAX));

	/* Convert time to register value */
	uint8_t value = time / mintime;

	printk("Set downshift time to %u ms (reg value 0x%x)", time, value);

	int err = reg_write(dev, reg_addr, value);
	if (err) {
		printk("Failed to change downshift time");
	}

	return err;
}

static int update_sample_time(const struct device *dev,
			      uint8_t reg_addr_lower,
			      uint8_t reg_addr_upper,
			      uint32_t sample_time)
{
	/* Set sample time for the Rest1-Rest3 modes.
	 * Values above 0x09B0 will trigger internal watchdog reset.
	 */
	uint32_t maxtime = 0x9B0;
	uint32_t mintime = 1;

	if ((sample_time > maxtime) || (sample_time < mintime)) {
		printk("Sample time %u out of range", sample_time);
		return -EINVAL;
	}

	printk("Set sample time to %u ms", sample_time);

	/* The sample time is (reg_value + 1) ms. */
	sample_time--;
	uint8_t buf[2];

	sys_put_le16((uint16_t)sample_time, buf);

	int err = reg_write(dev, reg_addr_lower, buf[0]);

	if (!err) {
		err = reg_write(dev, reg_addr_upper, buf[1]);
	} else {
		printk("Failed to change sample time");
	}

	return err;
}

static int toggle_rest_modes(const struct device *dev, uint8_t reg_addr,
			     bool enable)
{
	uint8_t value;
	int err = reg_read(dev, reg_addr, &value);

	if (err) {
		printk("Failed to read Config2 register");
		return err;
	}

	WRITE_BIT(value, PMW3360_REST_EN_POS, enable);

	printk("%sable rest modes", (enable) ? ("En") : ("Dis"));
	err = reg_write(dev, reg_addr, value);

	if (err) {
		printk("Failed to set rest mode");
	}

	return err;
}

static int pmw3360_async_init_fw_load_start(const struct device *dev)
{
	int err = 0;

	/* Read from registers 0x02-0x06 regardless of the motion pin state. */
	for (uint8_t reg = 0x02; (reg <= 0x06) && !err; reg++) {
		uint8_t buf[1];
		err = reg_read(dev, reg, buf);
	}

	if (err) {
		printk("Cannot read from data registers");
		return err;
	}

	/* Write 0 to Rest_En bit of Config2 register to disable Rest mode. */
	err = reg_write(dev, PMW3360_REG_CONFIG2, 0x00);
	if (err) {
		printk("Cannot disable REST mode");
		return err;
	}

	/* Write 0x1D in SROM_enable register to initialize the operation */
	err = reg_write(dev, PMW3360_REG_SROM_ENABLE, 0x1D);
	if (err) {
		printk("Cannot initialize SROM");
		return err;
	}

	return err;
}

static int pmw3360_async_init_fw_load_continue(const struct device *dev)
{
	int err;

	printk("Uploading optical sensor firmware...");

	/* Write 0x18 to SROM_enable to start SROM download */
	err = reg_write(dev, PMW3360_REG_SROM_ENABLE, 0x18);
	if (err) {
		printk("Cannot start SROM download");
		return err;
	}

	/* Write SROM file into SROM_Load_Burst register.
	 * Data must start with SROM_Load_Burst address.
	 */
	err = burst_write(dev, PMW3360_REG_SROM_LOAD_BURST,
			  pmw3360_firmware_data, pmw3360_firmware_length);
	if (err) {
		printk("Cannot write firmware to sensor");
	}

	return err;
}

static int pmw3360_async_init_fw_load_verify(const struct device *dev)
{
	int err;

	/* Read the SROM_ID register to verify the firmware ID before any
	 * other register reads or writes
	 */

	uint8_t fw_id;
	err = reg_read(dev, PMW3360_REG_SROM_ID, &fw_id);
	if (err) {
		printk("Cannot obtain firmware id");
		return err;
	}

	printk("Optical chip firmware ID: 0x%x", fw_id);
	if (fw_id != PMW3360_FIRMWARE_ID) {
		printk("Chip is not running from SROM!");
		return -EIO;
	}

	uint8_t product_id;
	err = reg_read(dev, PMW3360_REG_PRODUCT_ID, &product_id);
	if (err) {
		printk("Cannot obtain product id");
		return err;
	}

	if (product_id != PMW3360_PRODUCT_ID) {
		printk("Invalid product id!");
		return -EIO;
	}

	/* Write 0x20 to Config2 register for wireless mouse design.
	 * This enables entering rest modes.
	 */
	err = reg_write(dev, PMW3360_REG_CONFIG2, 0x20);
	if (err) {
		printk("Cannot enable REST modes");
	}

	return err;
}
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
int main(void)
{
	int err;

	// printk("Starting Bluetooth Peripheral HIDS mouse example\n");

	// if (IS_ENABLED(CONFIG_BT_HIDS_SECURITY_ENABLED)) {
	// 	err = bt_conn_auth_cb_register(&conn_auth_callbacks);
	// 	if (err) {
	// 		printk("Failed to register authorization callbacks.\n");
	// 		return 0;
	// 	}

	// 	err = bt_conn_auth_info_cb_register(&conn_auth_info_callbacks);
	// 	if (err) {
	// 		printk("Failed to register authorization info callbacks.\n");
	// 		return 0;
	// 	}
	// }

	/* DIS initialized at system boot with SYS_INIT macro. */
	// hid_init();

	// // err = bt_enable(NULL);
	// if (err) {
	// 	printk("Bluetooth init failed (err %d)\n", err);
	// 	return 0;
	// }

	// printk("Bluetooth initialized\n");

	// k_work_init(&hids_work, mouse_handler);
	// k_work_init(&adv_work, advertising_process);
	// if (IS_ENABLED(CONFIG_BT_HIDS_SECURITY_ENABLED)) {
	// 	k_work_init(&pairing_work, pairing_process);
	// }

	// if (IS_ENABLED(CONFIG_SETTINGS)) {
	// 	settings_load();
	// }

	// advertising_start();

	// configure_buttons();


    int ret = gpio_pin_configure_dt(&led, GPIO_OUTPUT_ACTIVE);
    if (ret < 0) {
        printk("Failed to configure LED pin");
        return;
    }

    printk("Blinking LED on P0.20\n");
	bt_conn_cb_register(&bluetooth_callbacks);
    remote_callbacks.notif_changed = remote_callbacks_s.notif_changed;

    err = bt_enable(bt_ready);
    if (err) {
        printk("bt_enable returned %d", err);
        return err;
    }

	k_sem_take(&bt_init_ok, K_FOREVER);

    err = bt_le_adv_start(BT_LE_ADV_CONN, ad, ARRAY_SIZE(ad), sd, ARRAY_SIZE(sd));
    if (err) {
        printk("Couldn't start advertising (err = %d)", err);
        return err;
    }

	// #define SPIOP	SPI_WORD_SET(8) | SPI_TRANSFER_MSB
	// static struct pmw3360_data data;
    // static const struct pmw3360_config config = {		       
	// 	.irq_gpio = 0,	       
	// 	.bus =  SPI_DT_SPEC_GET(DT_NODELABEL(gendev), SPIOP, 0),							       
	// 	.cs_gpio = GPIO_DT_SPEC_GET(DT_NODELABEL(spi0), cs_gpios),
	// };		
	

	while (1) {
		// k_sleep(K_SECONDS(1));
		gpio_pin_toggle_dt(&led);
        k_sleep(K_MSEC(3000));
		printk("Blinking LED on P0.20\n");

	// 	/* Battery level simulation */
		// bas_notify();
	}
}

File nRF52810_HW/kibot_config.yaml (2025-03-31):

kibot:
  version: 1

preflight:
  erc:
    enabled: true
    dir: fabrication_output/rule_checks
    format: ["HTML", "RPT"]
    output: "%f-%i%I%v.%x"
    dont_stop: false
  check_zone_fills: true

outputs:
  - name: 'gerbers'
    type: gerber
    dir: fabrication_output/manufacturing/gerbers_and_drills
    options:
      # generic layer options
      exclude_edge_layer: true
      exclude_pads_from_silkscreen: false
      plot_sheet_reference: false
      plot_footprint_refs: true
      plot_footprint_values: true
      force_plot_invisible_refs_vals: false
      tent_vias: true

      # gerber options
      line_width: 0.1
      subtract_mask_from_silk: false
      use_protel_extensions: false
      gerber_precision: 4.5
      create_gerber_job_file: true
      use_gerber_x2_attributes: true
      use_gerber_net_attributes: true

    layers:
      - F.Cu
      - B.Cu
      - In1.Cu
      - In2.Cu
      - F.SilkS
      - B.SilkS
      - F.Mask
      - B.Mask
      - User.Drawings
      - User.Comments
      - Edge.Cuts
      - F.Courtyard
      - B.Courtyard
      - F.Fab
      - B.Fab

  - name: 'drill_files'
    type: excellon
    dir: fabrication_output/manufacturing/gerbers_and_drills
    options:
      metric_units: true
      pth_and_npth_single_file: false

  - name: 'bom'
    comment: "Bill of Materials in CSV format"
    type: bom
    dir: fabrication_output/manufacturing

  - name: 'position'
    comment: "Pick and place file, JLC style"
    type: position
    dir: fabrication_output/manufacturing
    options:
      format: CSV

  - name: 'print_sch'
    comment: "Print schematic (PDF)"
    type: pdf_sch_print
    dir: fabrication_output
    options:
      output: schematic.pdf

  - name: "base"
    dir: fabrication_output/capture
    type: render_3d
    run_by_default: false
    options:
      ray_tracing: false
      width: 2000
      height: 1000

  - name: "top"
    comment: "Top view"
    dir: fabrication_output/capture
    type: render_3d
    extends: "base"
    options:
      rotate_x: 3
      rotate_z: -2
      output: "pcb_3d_render_top.png"

  - name: "bottom"
    comment: "Bottom view"
    dir: fabrication_output/capture
    type: render_3d
    extends: "top"
    options:
      width: 1920
      view: "bottom"
      output: "pcb_3d_render_bottom.png"

  - name: 'board_image_top'
    comment: "Image of PCB"
    type: pcbdraw
    dir: fabrication_output/capture
    options:
      bottom: false
      format: "png"
      output: "pcb_2d_image_top.png"

  - name: 'board_image_bottom'
    comment: "Image of PCB"
    type: pcbdraw
    dir: fabrication_output/capture
    options:
      bottom: true
      format: "png"
      output: "pcb_2d_image_bottom.png"

  - name: "interactive_bom"
    comment: "Interactive Bill of Materials (HTML)"
    type: ibom
    dir: fabrication_output/interactive_bom
    options:
      blacklist_empty_val: true

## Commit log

2024-07-24 First usable build with a custom board from sample example project
2024-07-27 Custom plank board renamed
2025-01-03 Considerate changes
    [nRF52810.kicad_pcb, nRF52810.kicad_sch]
2025-01-03 First draft design
    [nRF52810.kicad_pcb, nRF52810.kicad_sch]
2025-02-10 bump large
    [nRF52810.kicad_pcb, nRF52810.kicad_sch]
2025-02-11 Bulk change
    [nRF52810.kicad_pcb, nRF52810.kicad_sch]
2025-02-13 Custom board run from zephyr directory
2025-02-15 Custom buildable board with BT
2025-02-28 LED blinking verified
2025-03-31 SPI comm on, but PMW does not react
